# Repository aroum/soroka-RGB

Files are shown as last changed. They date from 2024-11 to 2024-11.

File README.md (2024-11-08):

# soroka RGB - DIY-Friendly 40% keyboard

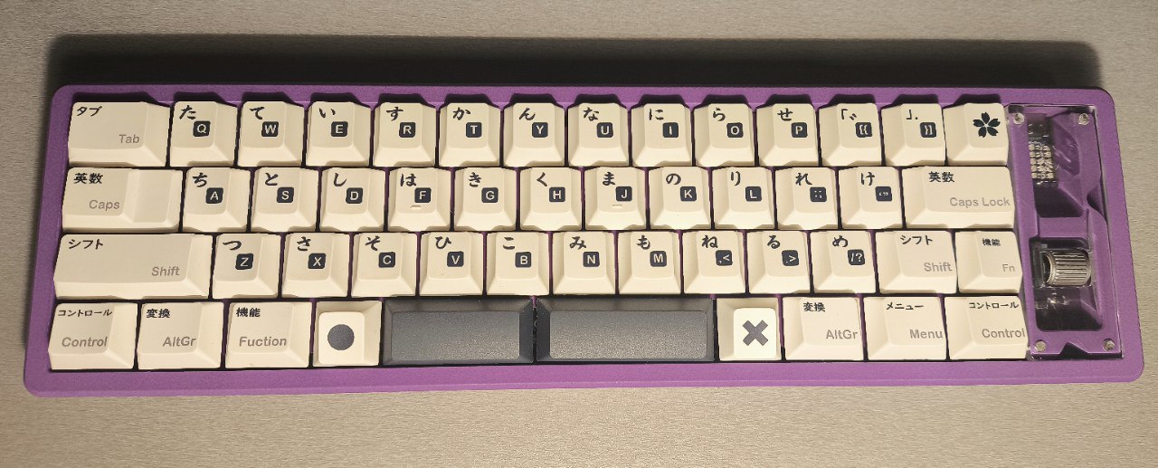
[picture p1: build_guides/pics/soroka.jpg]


This is a fork of the [Soroka](https://github.com/kapee1/soroka/) project with added support for the RP2040-Zero-matrix. The only modifications are to the spacer (v2), which includes a cutout to improve the viewing angle, and the addition of two optional pads on the board (v2). However, you can also use the original files with minor adjustments—see the Build Guide for more details.

### Build guide [[EN]](https://github.com/kapee1/soroka/blob/main/build%20guides/Soroka%20v2%20Build%20guide%20%5BEN%5D.md) | [[RU]](https://github.com/kapee1/soroka/blob/main/build%20guides/Soroka%20v2%20Build%20guide%20%5BRU%5D.md)

__Parts for v1 and v2 are not compatible!__

### Main features:

* Easy to build. Great for soldering practice.
* Supports all cyrillic symbols in base layer.
* Compatible with most base-kit keycap sets. No 40s addons needed.
* Optional Panasonic EVQWGD001 or EC-11 encoder
* Plate also optional. You can build keyboard without a plate to reduce cost.
* Variable bottom-row with a 3u spacebars support.
* Customizable magnet panels
* RGB matrix display 5x5
* [ZMK Studio](https://github.com/aroum/zmk-soroka)

### RGB


### Layout:


### Sizes:
sizes

## BOM:
| Part | Quantity |
|---|---|
| Soroka PCB | 1 | 
| Soroka Plate (Optional) | 1 | 
| Soroka Case | 1 | 
| Soroka Panel  (clear) | 1 | 
| Soroka Spacer (mod) | 1 | 
| RP2040-Zero-matrix (unsoldered pins) | 1 | 
| 1N4148w SOD-123 Diodes | 50  | 
| Panasonic EVQWGD001 (optional)| 1 |  
| Oval feets 22x4x1.5mm | 4 |  
| Silicone washers 2x5x1 | 9 |
| M2 x 4mm Screws | 13  |  
| M2 Inserts 3mm (OD3.2) | 13  |  
| Round magnets 3x1 mm | 8 |

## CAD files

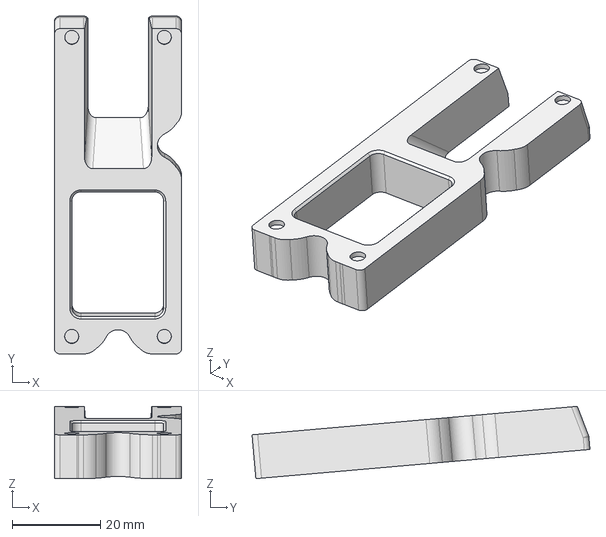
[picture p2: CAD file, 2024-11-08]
v2/case/soroka_v2_RGB_spacer.stp
28.9 x 76.8 x 16.4 mm

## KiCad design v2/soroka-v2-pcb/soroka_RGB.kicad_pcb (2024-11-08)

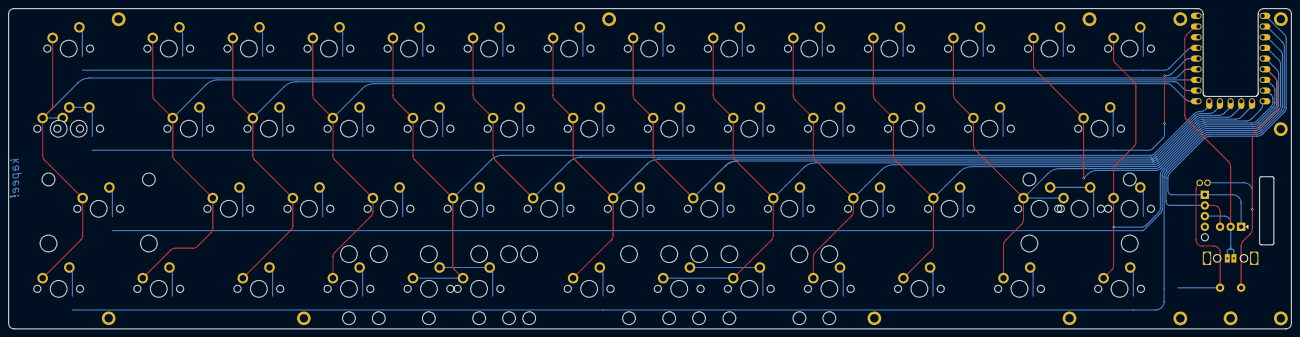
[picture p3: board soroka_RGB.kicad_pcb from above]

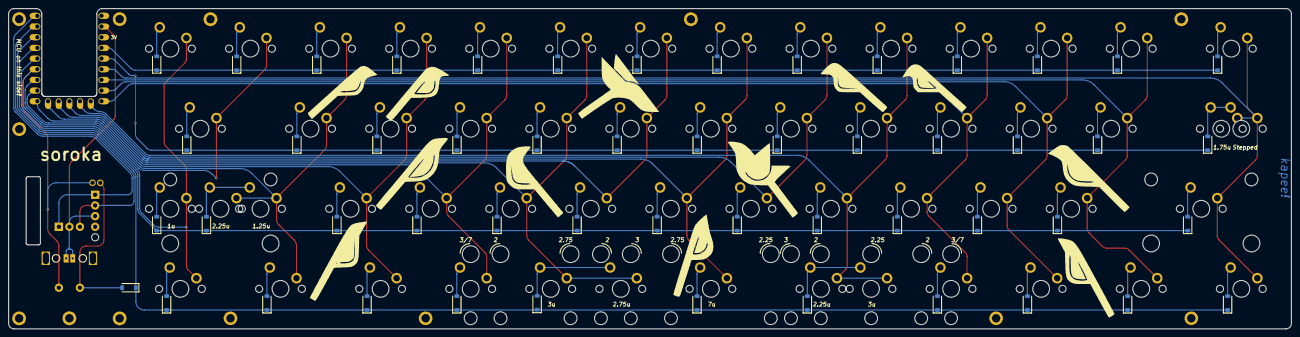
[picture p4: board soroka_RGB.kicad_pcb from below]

Board: 2 copper layers, 305.2 x 76.2 mm, 115 parts (52 on the bottom side), 73 nets.

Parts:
D1, D2, D3, D4, D5, D6, D7, D8, D9, D10, D11, D12, D13, D14, D15, D16, D17, D18, D19, D20, D21, D22, D23, D24, D25, D26, D27, D28, D29, D30, D31, D32, D33, D34, D35, D36, D37, D38, D39, D40, D41, D42, D43, D44, D45, D46, D47, D48, D49, D50, D51, D52: 1N4148W; D_SOD-123
MP: (no value)
RSW1, RSW1#2: SW_PUSH; SW_3x4x2_2legs_x2
SW1: MX150
SW2, SW3#2, SW4, SW5, SW6, SW7, SW8, SW9, SW10, SW11, SW12, SW13, SW14, SW16, SW17, SW18, SW19, SW20, SW21, SW22, SW23, SW24, SW25, SW26, SW29, SW30, SW31, SW32, SW33, SW34, SW35, SW36, SW37, SW38, SW45, SW50: MX100
SW3: Rotary_Encoder_Switch; EVQWGD001
SW15: Stepped; MX125
SW27: MX175
SW28: MX225R; MX225
SW39: 1.25u; MX125
SW40: 2.25u; MX225
SW41: 1u; MX100
SW42, SW43, SW44, SW51, SW52, SW53: MX125
SW46, SW49: 3u; MX300R
SW47: 2.25u; MX225R
SW48: 7u; MX100
SW54: 2.75u; MX275R
SW55: RotaryEncoder_Switch; RotaryEncoder_Alps_EC11E-Switch_Vertical_H20mm
SW55#2: 1.75u; MX175
SW**: MX200R
SW**#2: MX200R
U1: RP2040-Zero; MCU_rp2040-zero-tht

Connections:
COL0: SW1.2 (Row), SW15.2 (Row), SW28.2 (Row), SW42.2 (Row), SW55#2.2, U1.18
COL1: SW2.2 (Row), SW16.2 (Row), SW29.2 (Row), SW43.2 (Row), U1.17
COL2: SW3#2.2 (Row), SW17.2 (Row), SW30.2 (Row), SW44.2 (Row), U1.16
COL3: SW4.2 (Row), SW18.2 (Row), SW31.2 (Row), SW45.2 (Row), U1.15
COL4: SW5.2 (Row), SW19.2 (Row), SW32.2 (Row), SW46.2 (Row), SW47.2 (Row), U1.14
COL5: SW6.2 (Row), SW20.2 (Row), SW33.2 (Row), U1.13
COL6: SW7.2 (Row), SW21.2 (Row), SW34.2 (Row), SW48.2 (Row), U1.12
COL7: SW8.2 (Row), SW22.2 (Row), SW35.2 (Row), U1.11
COL8: SW9.2 (Row), SW23.2 (Row), SW36.2 (Row), SW49.2 (Row), SW54.2 (Row), U1.10
COL9: SW10.2 (Row), SW24.2 (Row), SW37.2 (Row), SW50.2 (Row), U1.9
COL10: SW11.2 (Row), SW25.2 (Row), SW38.2 (Row), SW51.2 (Row), U1.8
COL11: SW12.2 (Row), SW26.2 (Row), SW39.2 (Row), SW40.2 (Row), SW52.2 (Row), U1.7
COL12: SW3.S2, SW13.2 (Row), SW27.2 (Row), SW55.S2, U1.6
COL13: SW14.2 (Row), SW41.2 (Row), SW53.2 (Row), U1.5
ENC_CCW: SW3.A, SW55.A, U1.1
ENC_CW: SW3.B, SW55.B, U1.2
GND: RSW1.2, RSW1#2.1, SW3.C, SW55.C, U1.22
unnamed: D1.2 (A), SW1.1 (Col)
unnamed: D2.2 (A), SW2.1 (Col)
unnamed: D3.2 (A), SW3#2.1 (Col)
unnamed: D4.2 (A), SW4.1 (Col)
unnamed: D5.2 (A), SW5.1 (Col)
unnamed: D6.2 (A), SW6.1 (Col)
unnamed: D7.2 (A), SW7.1 (Col)
unnamed: D8.2 (A), SW8.1 (Col)
unnamed: D9.2 (A), SW9.1 (Col)
unnamed: D10.2 (A), SW10.1 (Col)
unnamed: D11.2 (A), SW11.1 (Col)
unnamed: D12.2 (A), SW12.1 (Col)
unnamed: D13.2 (A), SW13.1 (Col)
unnamed: D14.2 (A), SW14.1 (Col)
unnamed: D15.2 (A), SW15.1 (Col), SW55#2.1
unnamed: D16.2 (A), SW16.1 (Col)
unnamed: D17.2 (A), SW17.1 (Col)
unnamed: D18.2 (A), SW18.1 (Col)
unnamed: D19.2 (A), SW19.1 (Col)
unnamed: D20.2 (A), SW20.1 (Col)
unnamed: D21.2 (A), SW21.1 (Col)
unnamed: D22.2 (A), SW22.1 (Col)
unnamed: D23.2 (A), SW23.1 (Col)
unnamed: D24.2 (A), SW24.1 (Col)
unnamed: D25.2 (A), SW25.1 (Col)
unnamed: D26.2 (A), SW26.1 (Col)
unnamed: D27.2 (A), SW27.1 (Col)
unnamed: D28.2 (A), SW28.1 (Col)
unnamed: D29.2 (A), SW29.1 (Col)
unnamed: D30.2 (A), SW30.1 (Col)
unnamed: D31.2 (A), SW31.1 (Col)
unnamed: D32.2 (A), SW32.1 (Col)
unnamed: D33.2 (A), SW33.1 (Col)
unnamed: D34.2 (A), SW34.1 (Col)
unnamed: D35.2 (A), SW35.1 (Col)
unnamed: D36.2 (A), SW36.1 (Col)
unnamed: D37.2 (A), SW37.1 (Col)
unnamed: D38.2 (A), SW38.1 (Col)
unnamed: D39.2 (A), SW39.1 (Col), SW40.1 (Col)
unnamed: D40.2 (A), SW3.S1, SW55.S1
unnamed: D41.2 (A), SW41.1 (Col)
unnamed: D42.2 (A), SW53.1 (Col)
unnamed: D43.2 (A), SW52.1 (Col)
unnamed: D44.2 (A), SW51.1 (Col)
unnamed: D45.2 (A), SW50.1 (Col)
unnamed: D46.2 (A), SW49.1 (Col), SW54.1 (Col)
unnamed: D47.2 (A), SW48.1 (Col)
unnamed: D48.2 (A), SW46.1 (Col), SW47.1 (Col)
unnamed: D49.2 (A), SW45.1 (Col)
unnamed: D50.2 (A), SW44.1 (Col)
unnamed: D51.2 (A), SW43.1 (Col)
unnamed: D52.2 (A), SW42.1 (Col)
ROW0: D1.1 (K), D2.1 (K), D3.1 (K), D4.1 (K), D5.1 (K), D6.1 (K), D7.1 (K), D8.1 (K), D9.1 (K), D10.1 (K), D11.1 (K), D12.1 (K), D13.1 (K), D14.1 (K), U1.20
ROW1: D15.1 (K), D16.1 (K), D17.1 (K), D18.1 (K), D19.1 (K), D20.1 (K), D21.1 (K), D22.1 (K), D23.1 (K), D24.1 (K), D25.1 (K), D26.1 (K), D27.1 (K), U1.19
ROW2: D28.1 (K), D29.1 (K), D30.1 (K), D31.1 (K), D32.1 (K), D33.1 (K), D34.1 (K), D35.1 (K), D36.1 (K), D37.1 (K), D38.1 (K), D39.1 (K), D41.1 (K), U1.4
ROW3: D40.1 (K), D42.1 (K), D43.1 (K), D44.1 (K), D45.1 (K), D46.1 (K), D47.1 (K), D48.1 (K), D49.1 (K), D50.1 (K), D51.1 (K), D52.1 (K), U1.3

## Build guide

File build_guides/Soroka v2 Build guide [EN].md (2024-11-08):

Soroka v2 Build Guide [EN]

Any translation help would be appreciated 

### Necessary Tools:
- A soldering iron with temperature control and a thin cone tip

An example of a suitable soldering tip for installing inserts:


- Two thin metal tweezers, one of them can be replaced with any jumper
- Flux for soldering and solder
- Copper braid for removing solder (in case of problems with soldering, optional)
- desoldering pump (optional)
- Screwdriver or hexagon
- Superglue
- Toothpick or match
- Isopropyl alcohol or Flux-OFF
- Wipes or rag to clean excess flux

### Necessary details:
- Soroka v2 PCB, 1 pc
- Soroka v2 Plate, 1 pc
- Soroka v2 Case, 1 pc
- Soroka Spacer, 1 pc
- Diodes 1N4148W, SOD-123, 51 pcs
- RP-2040 Zero, 1 pc
- Fused inserts M2, 13 pcs- M2 screws, 4 mm, 13 pcs
- Oval legs 22x4x1.5mm, 4 pcs
- Silicone washers 5 x 2 x 1, 9 pcs
- Neodymium magnets 3mm x 1mm, 8 pcs
- Panasonic EVQWGD001 or 12.5 mm EC11 encoder (Optional), 1 pc

### PCB assembly
**1. Check the functionality of the controller.**
To do this, connect the controller to the computer using a USB cable, the LED on it will start flashing. Then you need to hold down the BOOT button and at the same time click RESET. The computer should detect the new device and open the drive folder. You can immediately upload the firmware file in .uf2 format by simply dragging the file to a folder. After copying the file, the drive should automatically reboot and exit firmware mode.

**2. Install diodes.**
It is necessary to apply a flux on the landing pads of the diodes. Better to go through the rows one by one. Apply the flux to one row, solder the diodes, and then repeat 3 more times. Diodes have a polarity, so it is important to place them on the right side. There is a cathode mark on the diode (a light strip on the body, on the side of one of the terminals), it must be positioned on the closed side of the white rectangle on the board. An example in the photo:


**3. Install the controller.**
The controller must be positioned on the same side as the diodes. The controller buttons should be inside the cutout on the board and look at the front (upper) surface of the board.


For smooth and easy installation, use pins. Before placing the controller, it is necessary to apply the flux to the pads on the board and the controller.
**IMPORTANT NOTE! The pins are used ONLY for alignment, they DO NOT NEED to be soldered.** 
I install the pins on the bottom and left side and solder the pads on the remaining one. After that, I take out the pins and solder the rest of the controller pads.


Now you need to desolder buttons 3 and 4; otherwise, they will press against the case. If you have already flashed the controller, you likely won't need these buttons anymore. However, if you're using a Panasonic encoder or building without an encoder, you can solder wires to the lower pads where the buttons were located.

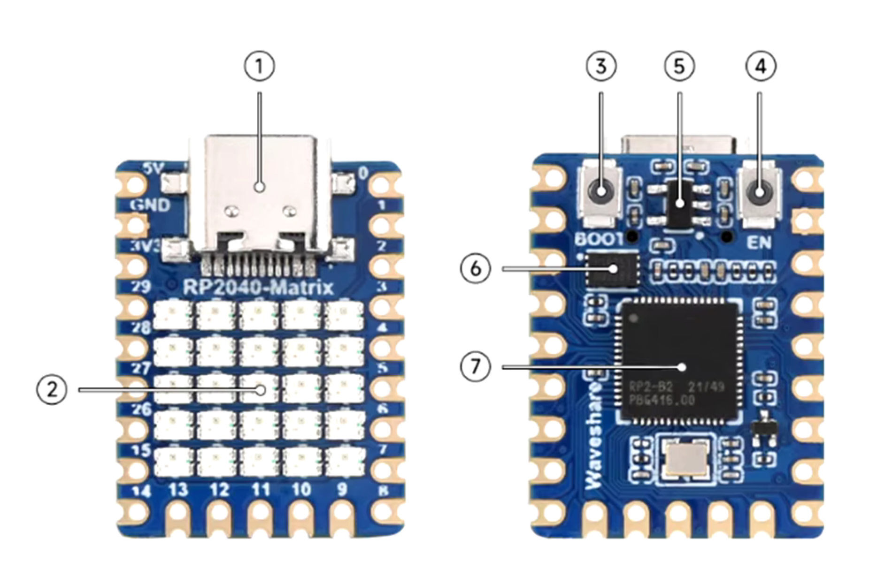
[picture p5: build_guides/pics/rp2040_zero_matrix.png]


Solder the other end of the wires to the encoder’s mounting holes. This is also where the buttons are connected. If you’re using the original version of the board, connect the remaining button pins to GND. The nearest GND point is the third pin of the encoder, and you can carefully route wires through the lower two holes. For added stability, you can glue the buttons to the board.

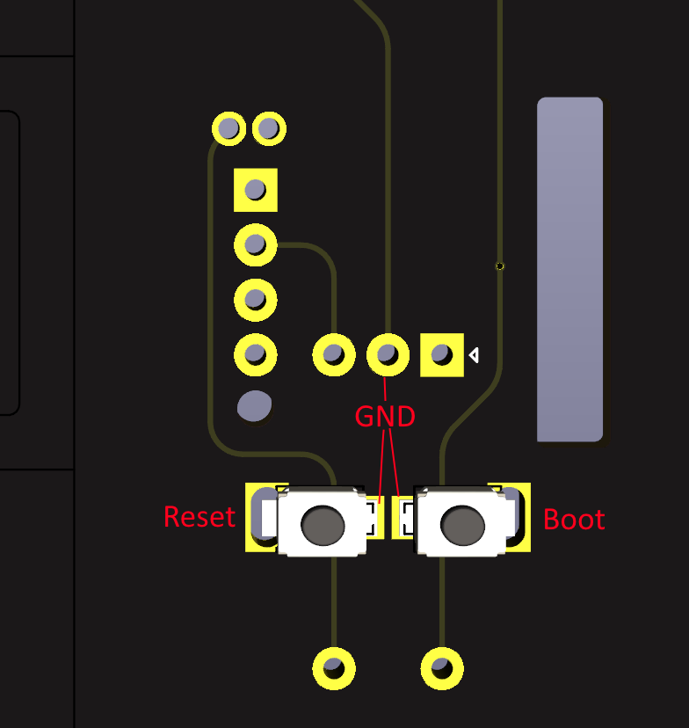
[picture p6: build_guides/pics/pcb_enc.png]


**4. Install the encoder and solder the encoder.**
In the case of a Panasonic encoder, it is necessary to "hook" it to the board, and then solder all the pins.
A "hook" that must be hooked onto the board


**5. Wash off all flux stains from the board.**
Apply alcohol or cleaner and remove everything with a dry cloth or napkin. In some cases, you can brush off heavy stains with a toothbrush.

**6. Check the PCB after soldering.**
After the board dries, connect the USB cable. If you didn't upload firmware yet, see step 1. 
The verification:
- Launch the VIAL- Go to the Layout tab and set all the desired options


- Go to the Matrix tester tab and click on the Unlock button


- Use two tweezers to connect the pins of the first two switches in the first row and wait for the unlock progress bar to fill up. 
- Using tweezers, close the contact pads of all switches. This will make sure that soldering is done without any mistakes.
- If individual buttons do not work, it is necessary to check the soldering of the corresponding diodes, if the whole row or column does not work, it is necessary to check the soldering of the controller pads.
**7. Install the switches in the plate (optional) and solder the switches with the desired layout**.
Carefully remove excess flux, if any. 

**8. Congratulations, you are amazing!**

### Assembling the rest of the keyboard
**0. Install silicone feet on the bottom of the case**



**1. Melt the inserts into the seats inside the case**.
To do this, install the insert into the mounting hole of the case, and with a heated soldering iron, slowly lower it down.
IMPORTANT! The soldering iron must be held perpendicular to the plane of the inner bottom. No need to put extra effort into it. If the insert is hard to enter, increase the temperature slightly or wait until all the parts are sufficiently heated._ 

**2. Melt the inserts into the spacer under the panel.**
The inserts are located closer to the edges, the holes under them are deeper. Here's the right side:



**3. Glue the magnets into the spacer.**
I recommend doing everything one at a time, so as not to get confused with the polarity of the magnets, otherwise it will be impossible to get them, the part will be damaged.
Places to install magnets:



The sequence is as follows:
- Squeeze a drop of superglue onto a piece of paper or thick cardboard
- Use a toothpick to apply a little glue into the magnet hole 
- Install the magnet and remove excess glue
- Repeat this operation for all spacer magnets.

**4. Glue the magnets to the lid.**
It is very important to glue the side. The sequence of actions: 
- Place the magnets on the already glued spacer magnets. This will allow you to find out the polarity and which side will need to be glued.
- To eliminate errors, you can put dots with a marker on the visible surface of the magnet. This will be the side that will be placed inside the lid. 
- Glue the magnets alternately, as was done for the spacer. A dot from the marker INSIDE the lid.

**5. Screw the spacer to the PCB with screws.** 
The location of the screws for the spacer:



**6. Install silicone washers inside the housing seats**
Places where silicone washers are installed:



**7. Install the finished PCB inside the case by screwing in the screws.** 

**8. Install a magnetic lid and keycaps**

### Done!

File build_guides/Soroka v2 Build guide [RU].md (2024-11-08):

Soroka v2 RGB Build Guide [RU]

### Необходимые инструменты и расходники:

- Паяльник с регулировкой температуры и тонкое конусное жало  
    Фото для примера:  



Пример подходящего жала для установки инсертов

- Два тонких металлических пинцета, один из них можно заменить любой перемычкой типа скрепки
- Флюс для пайки и припой
- Медная оплетка для удаления припоя (в случае проблем с пайкой, опционально)
- Оловоотсос (опционально)
- Отвертка или шестигранник
- Суперклей
- Зубочистка или спичка
- Изопропиловый спирт или Flux-OFF
- Салфетки или тряпка для очистки излишков флюса

### Необходимые детали:

- Soroka v2 PCB, 1 шт
- Soroka v2 Plate, 1  шт
- Soroka v2 Case, 1  шт
- Soroka Spacer, 1  шт
- Диоды 1N4148W, SOD-123, 51  шт
- RP-2040 Zero matrix, 1  шт
- Вплавляемые инсерты M2, 13  шт
- M2 винты, 4 мм, 13  шт    
- Овальные ножки 22x4x1.5mm, 4 шт
- Силиконовые шайбы 5 x 2 x 1, 9  шт
- Неодимовые магниты 3мм x 1мм, 8  шт
- Panasonic EVQWGD001 или 12.5 mm EC11 энкодер (Опционально), 1  шт
- Проводок для подключение кнопок на контроллере (Опционально), 2  шт

### Сборка PCB

**1. Проверить работоспособность контроллера.**

Для этого подключите контроллер к компьютеру с помощью USB кабеля, светодиод на нем начнет мигать.   
Затем необходимо зажать кнопку BOOT и в это же время кликнуть RESET. Компьютер должен обнаружить новое устройство и открыть папку накопителя. Можно сразу же закинуть файл прошивки в формате .uf2, просто перетащив файл в папку. После копирования файла, накопитель должен автоматически перезагрузится и выйти из режима прошивки. 

**2. Установить диоды.**

Необходимо смазать посадочные площадки диодов кисточкой с флюсом. Не стоит мазать все сразу, лучше идти по рядам. Нанести флюс на один ряд, припаять диоды, а затем повторить еще 3 раза.   
Диоды имеют полярность, поэтому важно располагать их нужно стороной.  
На диоде есть метка катода (светлая полоска на корпусе, со стороны одного из выводов), ее нужно расположить с замкнутой стороны белого прямоугольника на плате. Пример на фото: 



**3. Установить контроллер.**

Контроллер необходимо расположить на той же стороне, что и диоды. Кнопки контроллера должны оказаться внутри выреза на плате и смотреть на лицевую (верхнюю) поверхность платы.



Для ровной и простой установки, можно использовать комплектные пины.   
Перед размещением контроллера, необходимо нанести флюс на площадки на плате и контроллере.

**ВАЖНОЕ ЗАМЕЧАНИЕ! Гребенки используются ТОЛЬКО для выравнивания, их НЕ НУЖНО припаивать.** 

Я устанавливаю комплектную гребенку снизу и с еще одной стороны и припаиваю пады на оставшейся. После этого, вынимаю гребенки и припаиваю остальные площадки контроллера. 



Теперь необходимо отпаять кнопки 3 и 4, иначе они будут упираться в корпус. Если вы уже прошили контроллер, то эти кнопки, вероятно, больше не понадобятся. Однако в случае использования энкодера Panasonic или сборки без энкодера можно припаять к контроллеру провода на нижние контакты, где были кнопки.



Другой конец проводов нужно припаять к монтажным отверстиям энкодера. К этому же месту припаиваются кнопки. Если вы используете оригинальную версию платы, оставшиеся контакты кнопок нужно соединить с GND. Ближайшая точка GND — третий контакт энкодера, провод можно аккуратно провести через нижние два отверстия. Для надежности кнопки можно приклеить к плате.



**4. Установить энкодер и припаять энкодер.**

В случае энкодера Panasonic, необходимо "зацепить" его за плату, а затем припаять все пины. 



"Крюк", который необходимо зацепить за плату

**5. Отмыть все следы пайки и остатки флюса с платы.**

Обильно нанести спирт или очиститель и удалить все сухой тряпкой или салфеткой. В случае сильных загрязнений, можно оттереть сильные загрязнения зубной щеткой. 

**6. Проверить PCB после пайки.**

После высыхания платы, подключить USB-кабель. Если контроллер еще не прошит, см шаг 1.  
Последовательность проверки следующая:

- Запустить VIAL
- Перейти на вкладку Layout и установить все желаемые опции



- Перейти на вкладку Matrix tester и кликнуть на кнопку Unlock



- При помощи двух пинцетов замкнуть пины первых двух свитчей в первом ряду и дождаться пока прогресс-бар разблокировки заполнится. 
- С помощью пинцета поочередно замыкать контактные площадки всех свитчей. Это позволит убедится, что пайка выполнена без ошибок.
- В случае, если не работают отдельные кнопки - необходимо проверить пайку соответствующих диодов, если не работает целый ряд или колонка - необходимо проверить пайку площадок контроллера. 

**7. Установить свитчи в плейт (опционально) и запаять свитчи с нужным лейаутом**.

Аккуратно удалить излишки флюса, если они есть. 

**8. Поздравляю, вы восхитительны!**  
 

### Сборка остальной клавиатуры

**0. Установить силиконовые ножки на дно кейса**



**1. Заплавить инсерты в посадочные места внутри корпуса**.

Для этого установите инсерт в посадочное отверстие корпуса, и нагретым паяльником, медленно опускайте его в вниз.

_ВАЖНО! Паяльник нужно держать перпендикулярно плоскости внутреннего дна. Не нужно прикладывать лишних усилий. Если инсерт тяжело заходит, немного увеличьте температуру или подождите пока все детали достаточно нагреются._ 

**2. Заплавить инсерты в проставку под панель.**

Инсерты расположены ближе к краям, отверстия под них более глубокие. Вот правильная сторона: 



Места для установки инсертов

**3. Приклеить магниты в проставку.**

Рекомендую делать все поочередно, чтобы не запутаться с полярностью магнитов, иначе достать их будет невозможно, деталь будет испорчена.



Места для установки магнитов

Последовательность следующая:

- Выдавить каплю суперклея на листок бумаги или плотного картона
- С помощью зубочистки нанести немного клея в отверстие для магнита
- Установить магнит и удалить излишки клея

Повторить эту операцию для всех магнитов проставки. 

**4. Приклеить магниты для крышки.**

Очень важно приклеить нужно стороной. Последовательность действий: 

- Разместить магниты на уже приклеенных магнитах проставки. Это позволит узнать полярность и какой стороной нужно будет приклеивать.
- Чтобы исключить ошибки, можно поставить точки маркером на видимой поверхности магнита. Это будет та сторона, которая будет размещена внутри крышки. 
- Поочередно приклеивать магниты, как это было сделано для проставки. Точкой от маркера ВНУТРИ крышки.

**5. Прикрутить проставку к PCB винтами.** 



Расположение винтов для проставки

**6. Установить силиконовые шайбы внутри посадочных мест корпуса**



Места установки силиконовых шайб

**7. Установить готовую PCB внутри корпуса, прикрутив винтами.** 

**8. Установить крышкечку на магнитах и кейкапы**

### Готово!
